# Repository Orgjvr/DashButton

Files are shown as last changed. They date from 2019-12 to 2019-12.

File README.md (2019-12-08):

# DashButton
This is a IOT button which sends a MQTT message with the VCC voltage when pressed. Optimised for battery use.

I run it on an ESP-01 (actually an ESP8266 with the first form factor). It needs minimal connections, and works great from a 3.7V LiPo battery with an inline diode to drop the voltage a bit to ensure the safety of the ESP8266. 

I have multiple of these buttons in my home, and a cheap no-name 18650 battery last more than a year. Of course if you are going to do thousands of button presses, the battery will need replacement sooner. I do have some stats about the amount of button presses, but I need to analyse it, as the original version of the code, went into an infinite loop if it could not connect to either the Wifi, or the MQTT server. This depleted the batteries in no amount of time :) The newer version, will limit the amount of attempted connections, and if it could not connect, go back to sleep.

Todo:
  Add some photos of the development button.
  Get info of amount of button presses.

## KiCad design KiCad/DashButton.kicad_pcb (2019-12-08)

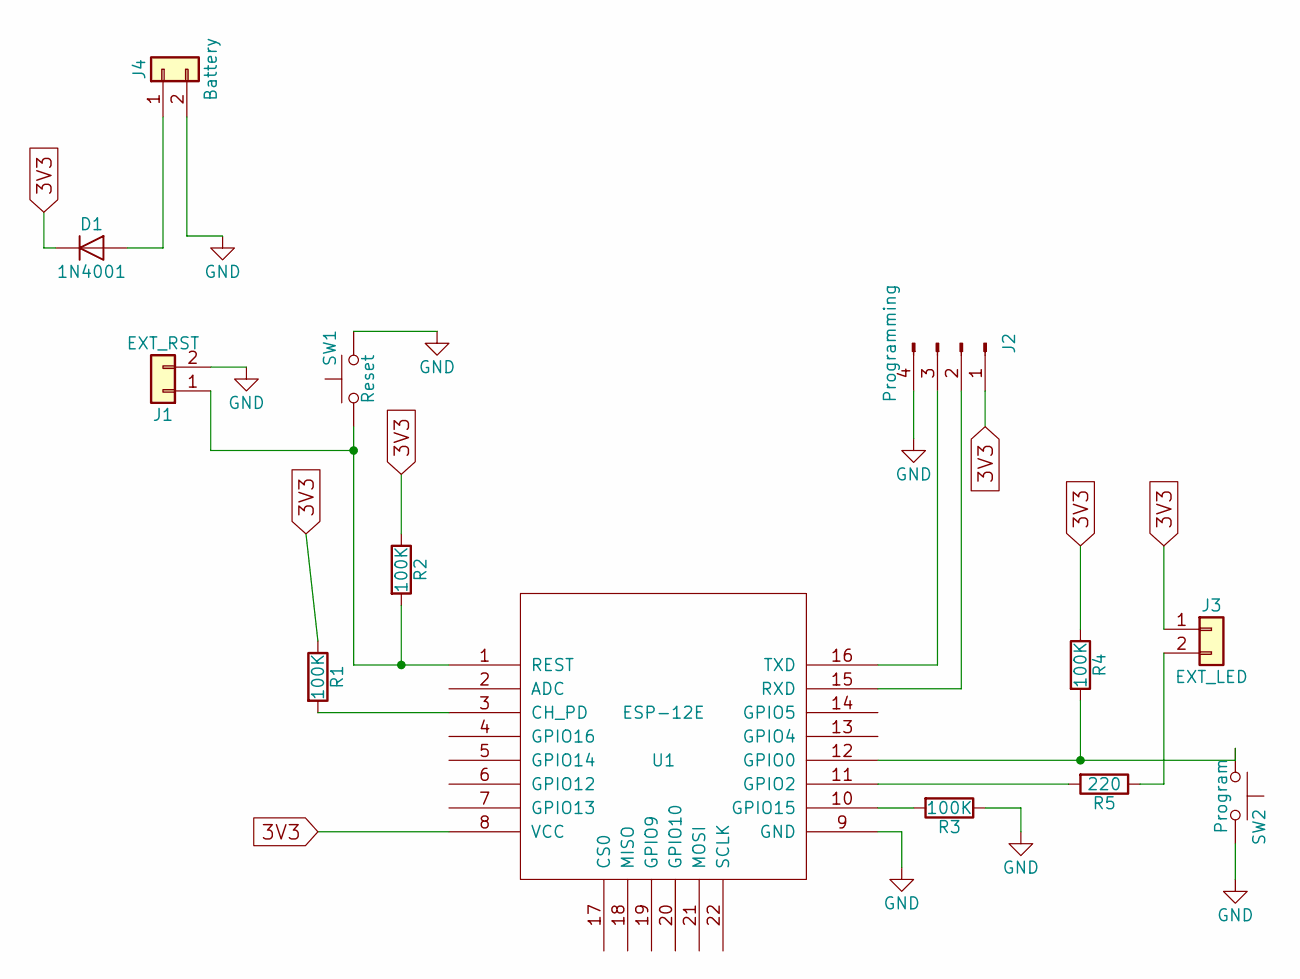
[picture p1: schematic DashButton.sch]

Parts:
D1: 1N4001; D_DO-41_SOD81_P7.62mm_Horizontal
J1: EXT_RST; Pin_Header_Straight_1x02_Pitch2.54mm
J2: Programming; Pin_Header_Straight_1x04_Pitch2.54mm
J3: EXT_LED; Pin_Header_Straight_1x02_Pitch2.54mm
J4: Battery; Pin_Header_Straight_1x02_Pitch2.54mm
R1, R2, R3, R4: 100K; R_Axial_DIN0411_L9.9mm_D3.6mm_P7.62mm_Vertical
R5: 220; R_Axial_DIN0411_L9.9mm_D3.6mm_P7.62mm_Vertical
SW1: Reset; SW_PUSH_6mm
SW2: Program; SW_PUSH_6mm
U1: ESP-12E; ESP-12E_SMD

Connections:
3V3: D1.1 (K), J2.1, J3.1, R1.1, R2.1, R4.1, U1.8 (VCC)
GND: J1.2, J2.4, J4.2, R3.1, SW1.2, SW2.2, U1.9 (GND)
unnamed: D1.2 (A), J4.1
unnamed: J1.1, R2.2, SW1.1, U1.1 (REST)
unnamed: J2.2, U1.15 (RXD)
unnamed: J2.3, U1.16 (TXD)
unnamed: J3.2, R5.1
unnamed: R1.2, U1.3 (CH_PD)
unnamed: R3.2, U1.10 (GPIO15)
unnamed: R4.2, SW2.1, U1.12 (GPIO0)
unnamed: R5.2, U1.11 (GPIO2)

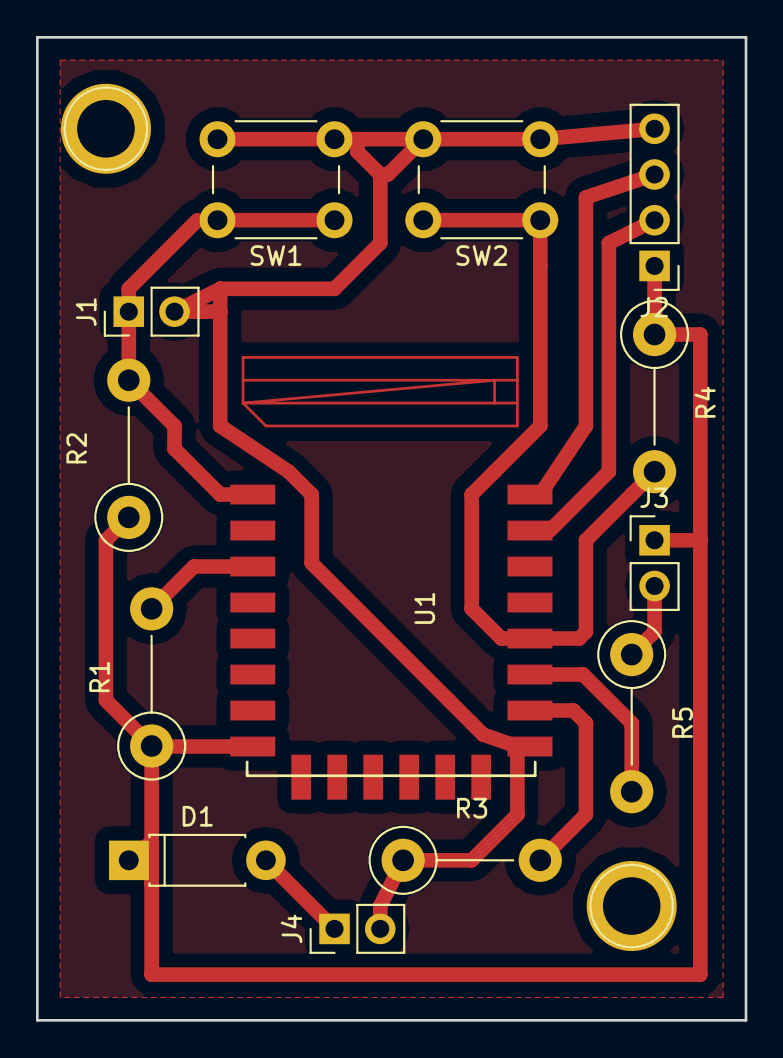
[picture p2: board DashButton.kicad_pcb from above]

Board: 2 copper layers, 39.4 x 54.6 mm, 13 parts (0 on the bottom side), 11 nets.

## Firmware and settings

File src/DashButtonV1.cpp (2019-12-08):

/*
  Battery Button V1
  2018/06/02
  by OrgJvR

  This code uses a state machine during the loop.
  Minimum requirements:
    1. A runnable ESP (check the minimum connections)
    2. A button between RST and GND. This will wake ESP and it will send a MQTT message.
  Optional requirements:
    1. A button to force ESP into setup mode (Need to define enableOTA)
    2. A LED to indicate status (Need to define USE_LED). Dont use GPIO0!

  ToDo:
    1. AP mode to setup Wifi and MQTT parameters.
    2. Maybe go to AP mode after 10 seconds if it cannot connect to wifi.
*/
//#define enableOTA // You need at least 1MB flash for OTA to work. If used, go to http://bb-webupdate.local in web browser.
//#define DEBUG // This cannot be used with enableOTA if SETUP_BUTTON=3!
//#define USE_LED

//**********************************************************************
// INCLUDE
//**********************************************************************
#include <Arduino.h>
#include <ESP8266WiFi.h>
#include <PubSubClient.h>
#include <WiFiClient.h>

// If you enable the define below, you need a file called private.h 
//    with the same lines as the ELSE below. This will not be uploaded to git.
#define hasPrivateCredentials 

#ifdef hasPrivateCredentials
  #include "private.h"
#else
  const char* ssid = "ssid";
  const char* password = "wifi_password";
  // MQTT
  const char* mqtt_server = "192.168.10.5";
  const char* mqtt_user = "mqttusername";
  const char* mqtt_pass = "mqttpassword";
  const int mqtt_port = 1883;
#endif


#ifdef enableOTA
  #include <ESP8266WebServer.h>
  #include <ESP8266mDNS.h>
  #include <ESP8266HTTPUpdateServer.h>
#endif

void setup_wifi();
void reconnect();
void getUID(char cMac[]) ;
void getInfo();

//**********************************************************************
// DEFINE
//**********************************************************************
#ifdef USE_LED
  //#define LED 2               // GPIO2 - Onboard LED op die ESP12
  #define LED 1               // GPIO1 - Onboard LED op die ESP01
#endif

#ifdef enableOTA
  // Button for Webupdate. Dont use GPIO0!
  //#define SETUP_BUTTON 12     // Use GPIO12 on ESP-12
  #define SETUP_BUTTON 3     // Use TX pin for Setup Button on ESP-01
#endif

//**********************************************************************
// PARAMETER
//**********************************************************************
// Wifi
#ifdef DEBUG
  unsigned long previousMillis = 0;   // will store last time LED was updated
  long sendtime = 0;                  // sendtime
#endif
#ifdef enableOTA
  const char* host = "bb-webupdate";
  const char* update_path = "/firmware";
  const char* update_username = "admin";
  const char* update_password = "BigButt";
#endif
char mqtt_clientId[10];
char outTopic[25] = "/BatteryButton/";

// Hardware
#ifdef USE_LED
  #ifndef DEBUG
    unsigned long previousMillis = 0;   // will store last time LED was updated
  #endif
  int ledState = HIGH;                // ledState used to set the LED
  const long interval = 500;          // interval at which to blink (milliseconds)
#endif
char msg[10];                       // message for mqtt publish
#ifdef enableOTA
  boolean mSetupButton = LOW;         // flag Setup Button
  int state = 0;                      // Stratup state for Statemachine
#else
  int state = 1;                      // Startup state for Statemachine
#endif
//**********************************************************************
// SETUP
//**********************************************************************
ADC_MODE (ADC_VCC);                 // VCC Read

#ifdef enableOTA
  ESP8266WebServer httpServer(80);
  ESP8266HTTPUpdateServer httpUpdater;
#endif

WiFiClient espClient;
PubSubClient client(espClient);

void setup() {
  #ifdef enableOTA
    pinMode(SETUP_BUTTON, INPUT_PULLUP);    // Webupdate Button
  #endif
  #ifdef USE_LED
    pinMode(LED, OUTPUT);                   // Onboard LED as Output
  #endif
  #ifdef DEBUG
    sendtime = millis();
    //  Serial.begin(115200);
    Serial.begin(74880);
  //Print Info about module;
  //getInfo();
  #endif

  
  // Setup Wifi
  setup_wifi();

  // Get mac
  #ifdef DEBUG
    Serial.println("getUID(mqtt_clientId):");
  #endif
  getUID(mqtt_clientId);
  #ifdef DEBUG
    Serial.print("mqtt_clientId:");
    Serial.println(mqtt_clientId);
  #endif
  strcat(outTopic,mqtt_clientId);
  
  // Setup MQTT
  client.setServer(mqtt_server, mqtt_port);

  // Setup httpUpdater
#ifdef enableOTA
  MDNS.begin(host);
  //httpUpdater.setup(&httpServer);
  httpUpdater.setup(&httpServer, update_path, update_username, update_password);
  httpServer.begin();
  MDNS.addService("http", "tcp", 80);
#endif
}

void setup_wifi() {
  int WaitTime = 0;
  int loop_cnt = 0;
  delay(10);
  // We start by connecting to a WiFi network
  #ifdef DEBUG
    Serial.println();
    Serial.print("Connecting to ");
    Serial.println(ssid);
  #endif
  WiFi.begin(ssid, password);

  while (WiFi.status() != WL_CONNECTED && loop_cnt < 50) {
    delay(50);
    WaitTime+=50;
    #ifdef DEBUG
      WaitTime+=450;
      delay(450); //delay a further 450ms to not flood the user with info
      Serial.print(".");
    #endif
    /*if (WaitTime>15000) {
      //After 15 seconds start the AP
      WiFi.disconnect();
      WiFi.softAP("softAP","123456789000", 1, false);
    }*/
    loop_cnt++;
  }

  #ifdef DEBUG
    Serial.println("");
    Serial.println("WiFi connected if valid ip address below");
    Serial.println("IP address: ");
    Serial.println(WiFi.localIP());
  #endif
}

void reconnect() {
  int loop_cnt = 0;
  // Loop until we're reconnected
  while (!client.connected() && loop_cnt < 10) {
    #ifdef DEBUG
      Serial.println("Attempting MQTT connection...");
    #endif
    // Client ID connected
    if (client.connect(mqtt_clientId, mqtt_user, mqtt_pass)) {
      #ifdef DEBUG
        Serial.print(mqtt_clientId);
        Serial.println(" connected");
      #endif
      // Once connected, publish an announcement...
      client.publish("outTopic", "connected");
    } else {
      #ifdef DEBUG
        Serial.print("failed, rc=");
        Serial.print(client.state());
        Serial.println(" try again in 5 seconds");
      #endif
      // Wait 5 seconds before retrying
      delay(500);
    }
    loop_cnt++;
  }
}

void getUID(char cMac[]) {
  byte mac[6];
  WiFi.macAddress(mac);
  for (int i = 3; i < 6; i++)
  {
        byte nib1 = (mac[i] >> 4) & 0x0F;
        byte nib2 = (mac[i] >> 0) & 0x0F;
        cMac[(i-3)*2+0] = nib1  < 0xA ? '0' + nib1  : 'A' + nib1  - 0xA;
        cMac[(i-3)*2+1] = nib2  < 0xA ? '0' + nib2  : 'A' + nib2  - 0xA;
  }
  cMac[6] = '\0';
}

void getInfo() {
  #ifdef DEBUG
    Serial.println();
    Serial.print("Chip ID: ");
    Serial.println(ESP.getFlashChipId());
    Serial.print("Chip Real Size: ");
    Serial.println(ESP.getFlashChipRealSize());
    Serial.print("Chip Size: ");
    Serial.println(ESP.getFlashChipSize());
    Serial.print("Chip Speed: ");
    Serial.println(ESP.getFlashChipSpeed());
    Serial.print("Chip Mode: ");
    Serial.println(ESP.getFlashChipMode());
  #endif
}


//**********************************************************************
// LOOP
//**********************************************************************
void loop() {

  #ifdef enableOTA
    // HTTPServer Handle Client
    httpServer.handleClient();
  #endif

  // MQTT Client
  if (!client.connected()) {
    reconnect();
  }
  client.loop();

  #ifdef DEBUG
    // LED blink when ESP is in Upload Mode
    unsigned long currentMillis = millis();

    #ifdef USE_LED
      if (currentMillis - previousMillis >= interval) {
        // save the last time you blinked the LED
        previousMillis = currentMillis;

        // if the LED is off turn it on and vice-versa:
        if ((ledState == LOW) && (mSetupButton = HIGH)) {
          ledState = HIGH;
        } else {
          ledState = LOW;
        }
        // set the LED with the ledState of the variable:
        digitalWrite(LED, ledState);
      }
    #endif
  #endif

  // Read the VCC from Battery
  float vcc = ESP.getVcc() / 1000.0;
  vcc = vcc - 0.12;     // correction value from VCC

  // StateMachine for send the telegram to MQTT
  switch (state) {
    case 0:    // SETUP
      #ifdef enableOTA
        if (digitalRead(SETUP_BUTTON) == LOW) {
          mSetupButton = HIGH;
          #ifdef DEBUG
            Serial.println("Webupdate started ...");
            Serial.printf("Open http://%s.local%s in your browser and login with username '%s' and password '%s'\n", host, update_path, update_username, update_password);
          #endif
          state = 0;
        } else {
          state = 1;
        }
        // This cause state machine to always stay in state 0 if it previously was in state 0 (Until reset).
        if (mSetupButton == HIGH) {
          state = 0;
        }
      #endif
      break;
    case 1:    // Send MQTT message
      dtostrf(vcc, sizeof(vcc), 2, msg);
      client.publish(outTopic, msg);
      #ifdef DEBUG
        Serial.print("VCC: ");
        Serial.print(msg);
        Serial.println("V");
      #endif
      state = 2;
      break;
    case 2:    // Debug and go to Deepsleep
      #ifdef DEBUG
        sendtime = millis() - sendtime;
        Serial.print("Sendtime: ");
        Serial.print(sendtime);
        Serial.println("ms");
        Serial.print("Good Night ...");
      #endif
      ESP.deepSleep(0, WAKE_RFCAL);
      break;
  }
  delay(100);  // delay in between reads for stability
}
